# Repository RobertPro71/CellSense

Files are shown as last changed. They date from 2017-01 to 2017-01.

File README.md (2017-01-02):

# CellSense
Measure voltage from a RC cell pack with up to 6 cells. 

To measure the voltage from a RC-Lipo-pack with high reselution. First two cells are convert with a voltage divider. To get the voltage from the second cell it is needed to subtract the voltage from the frist cell. All other cells are converted with a differential amplifier that have "over the top" inputs.

Convert cells from 0..4,5V (pack voltage 27V) to 0..2,5V.

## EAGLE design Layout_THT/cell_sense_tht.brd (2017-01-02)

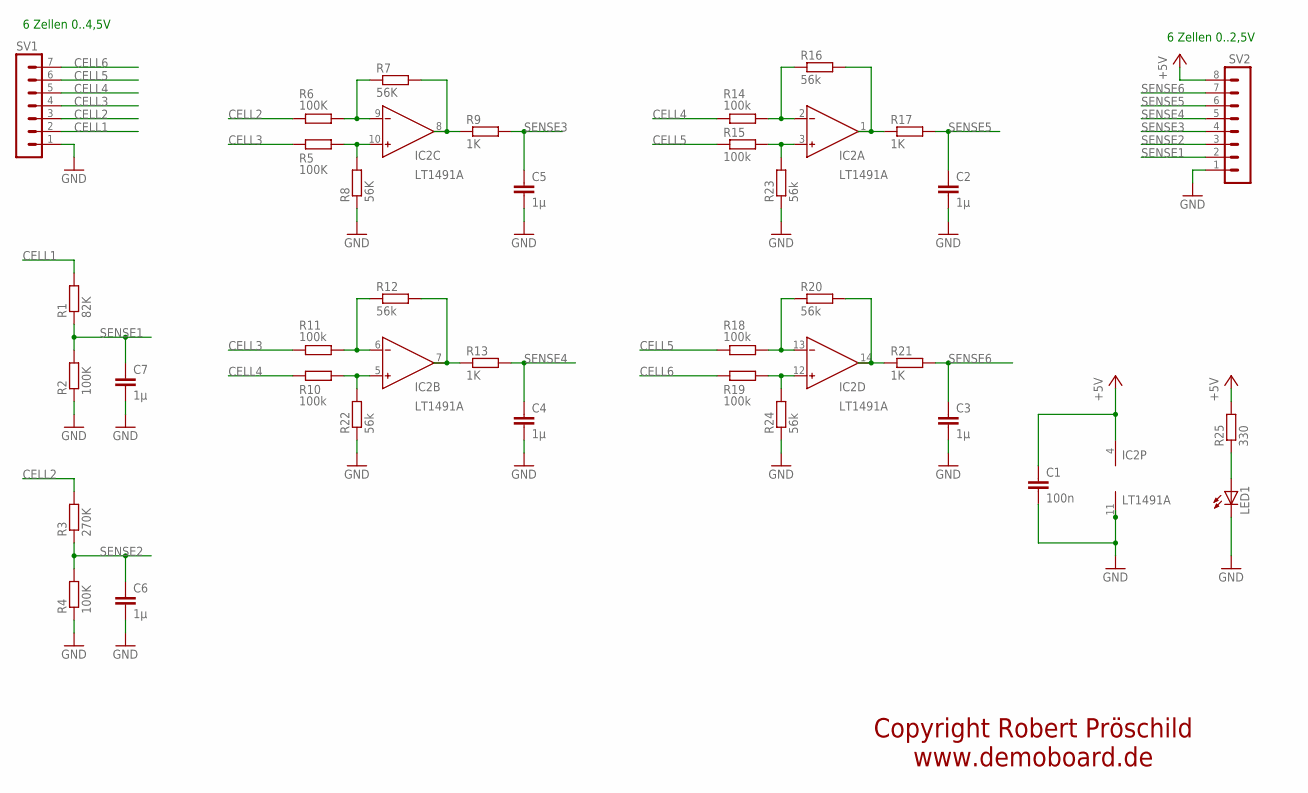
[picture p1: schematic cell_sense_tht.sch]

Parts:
C1: 100n; C025-024X044
C2, C3, C4, C5, C6, C7: 1µ; C025-024X044
IC2: LT1491A; DIL14
LED1: LED3MM
R1: 82K; 0204/7
R2, R4, R5, R6: 100K; 0204/7
R3: 270K; 0204/7
R7, R8: 56K; 0204/7
R9, R13, R17, R21: 1K; 0204/7
R10, R11, R14, R15, R18, R19: 100k; 0204/7
R12, R16, R20, R22, R23, R24: 56k; 0204/7
R25: 330; 0204/7
SV1: MA07-1
SV2: MA08-1

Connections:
+5V: C1.1, IC2.4 (V+), R25.2, SV2.8
CELL1: R1.2, SV1.2
CELL2: R3.2, R6.1, SV1.3
CELL3: R5.1, R11.1, SV1.4
CELL4: R10.1, R14.1, SV1.5
CELL5: R15.1, R18.1, SV1.6
CELL6: R19.1, SV1.7
GND: C1.2, C2.2, C3.2, C4.2, C5.2, C6.2, C7.2, IC2.11 (V-), LED1.K (C), R2.1, R4.1, R8.1, R22.1, R23.1, R24.1, SV1.1, SV2.1
unnamed: IC2.10 (IN+), R5.2, R8.2
unnamed: IC2.9 (IN-), R6.2, R7.1
unnamed: IC2.8 (OUT), R7.2, R9.1
unnamed: LED1.A, R25.1
unnamed: IC2.3 (IN+), R15.2, R23.2
unnamed: IC2.2 (IN-), R14.2, R16.1
unnamed: IC2.1 (OUT), R16.2, R17.1
unnamed: IC2.5 (IN+), R10.2, R22.2
unnamed: IC2.6 (IN-), R11.2, R12.1
unnamed: IC2.7 (OUT), R12.2, R13.1
unnamed: IC2.12 (IN+), R19.2, R24.2
unnamed: IC2.13 (IN-), R18.2, R20.1
unnamed: IC2.14 (OUT), R20.2, R21.1
SENSE1: C7.1, R1.1, R2.2, SV2.2
SENSE2: C6.1, R3.1, R4.2, SV2.3
SENSE3: C5.1, R9.2, SV2.4
SENSE4: C4.1, R13.2, SV2.5
SENSE5: C2.1, R17.2, SV2.6
SENSE6: C3.1, R21.2, SV2.7

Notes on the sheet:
6 Zellen 0..4,5V
6 Zellen 0..2,5V
Copyright Robert Pröschild www.demoboard.de

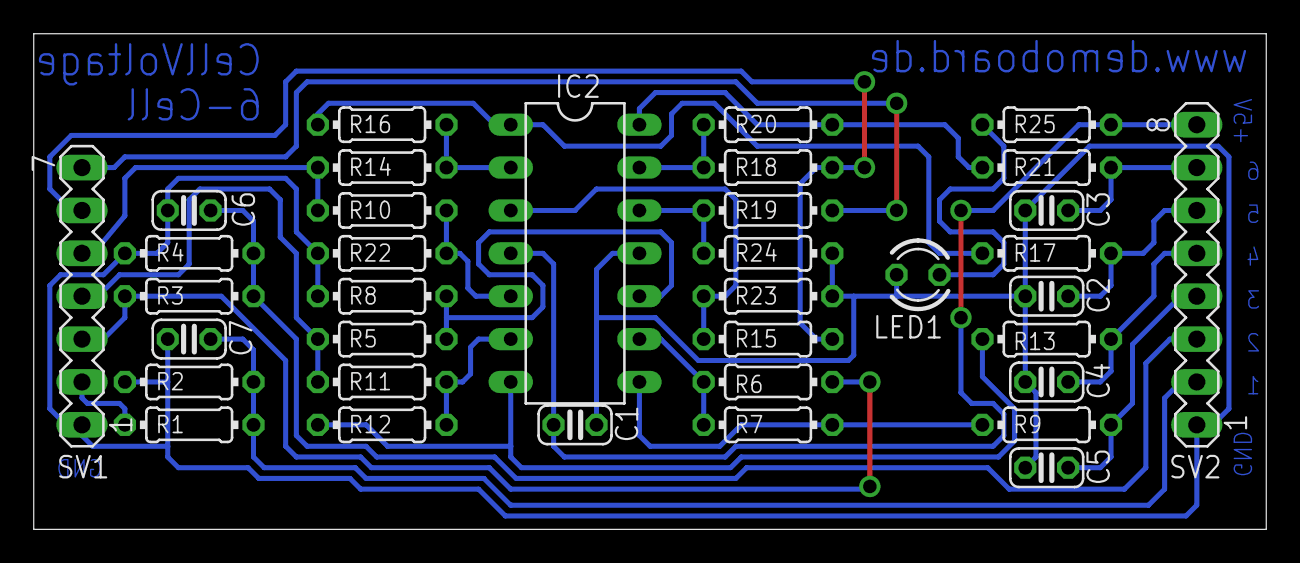
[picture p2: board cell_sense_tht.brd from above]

Board: 2 copper layers, 73.0 x 29.4 mm, 36 parts (0 on the bottom side), 27 nets.
